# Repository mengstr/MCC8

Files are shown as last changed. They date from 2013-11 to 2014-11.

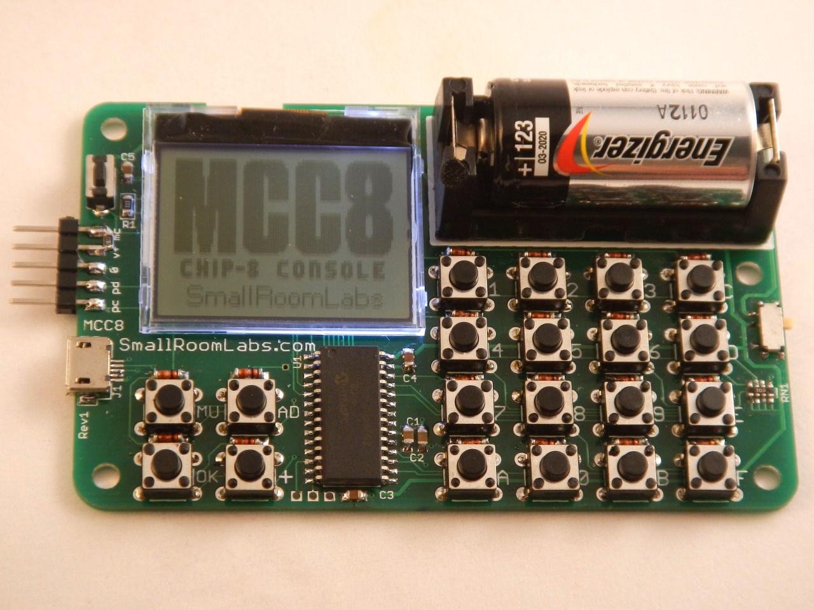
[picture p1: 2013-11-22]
Misc/BootScreen.jpg

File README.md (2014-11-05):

# MCC8

This is a small handheld PIC24-based CHIP-8 emulator game console. A cheap Noika 1202 LCD is used as the display and a CR123A 3 volt lithium battery for power. More info about the project can be found at [DangerousPrototypes.com](http://dangerousprototypes.com/forum/viewtopic.php?f=56&t=6018)



The sixteen buttons on the right is a hexadecimal keypad arranged in the same strange order as the COSMAC had for maximum keyplacement compability. Then I've added four extra buttons to go into game selection menu mode and other stuffs for future use. 

Read more about CHIP-8 at [Wikipedia](http://en.wikipedia.org/wiki/CHIP-8)

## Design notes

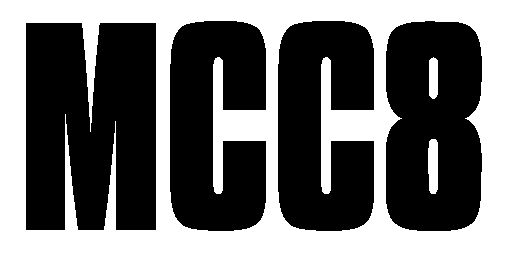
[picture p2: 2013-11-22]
Misc/mcc8.bmp

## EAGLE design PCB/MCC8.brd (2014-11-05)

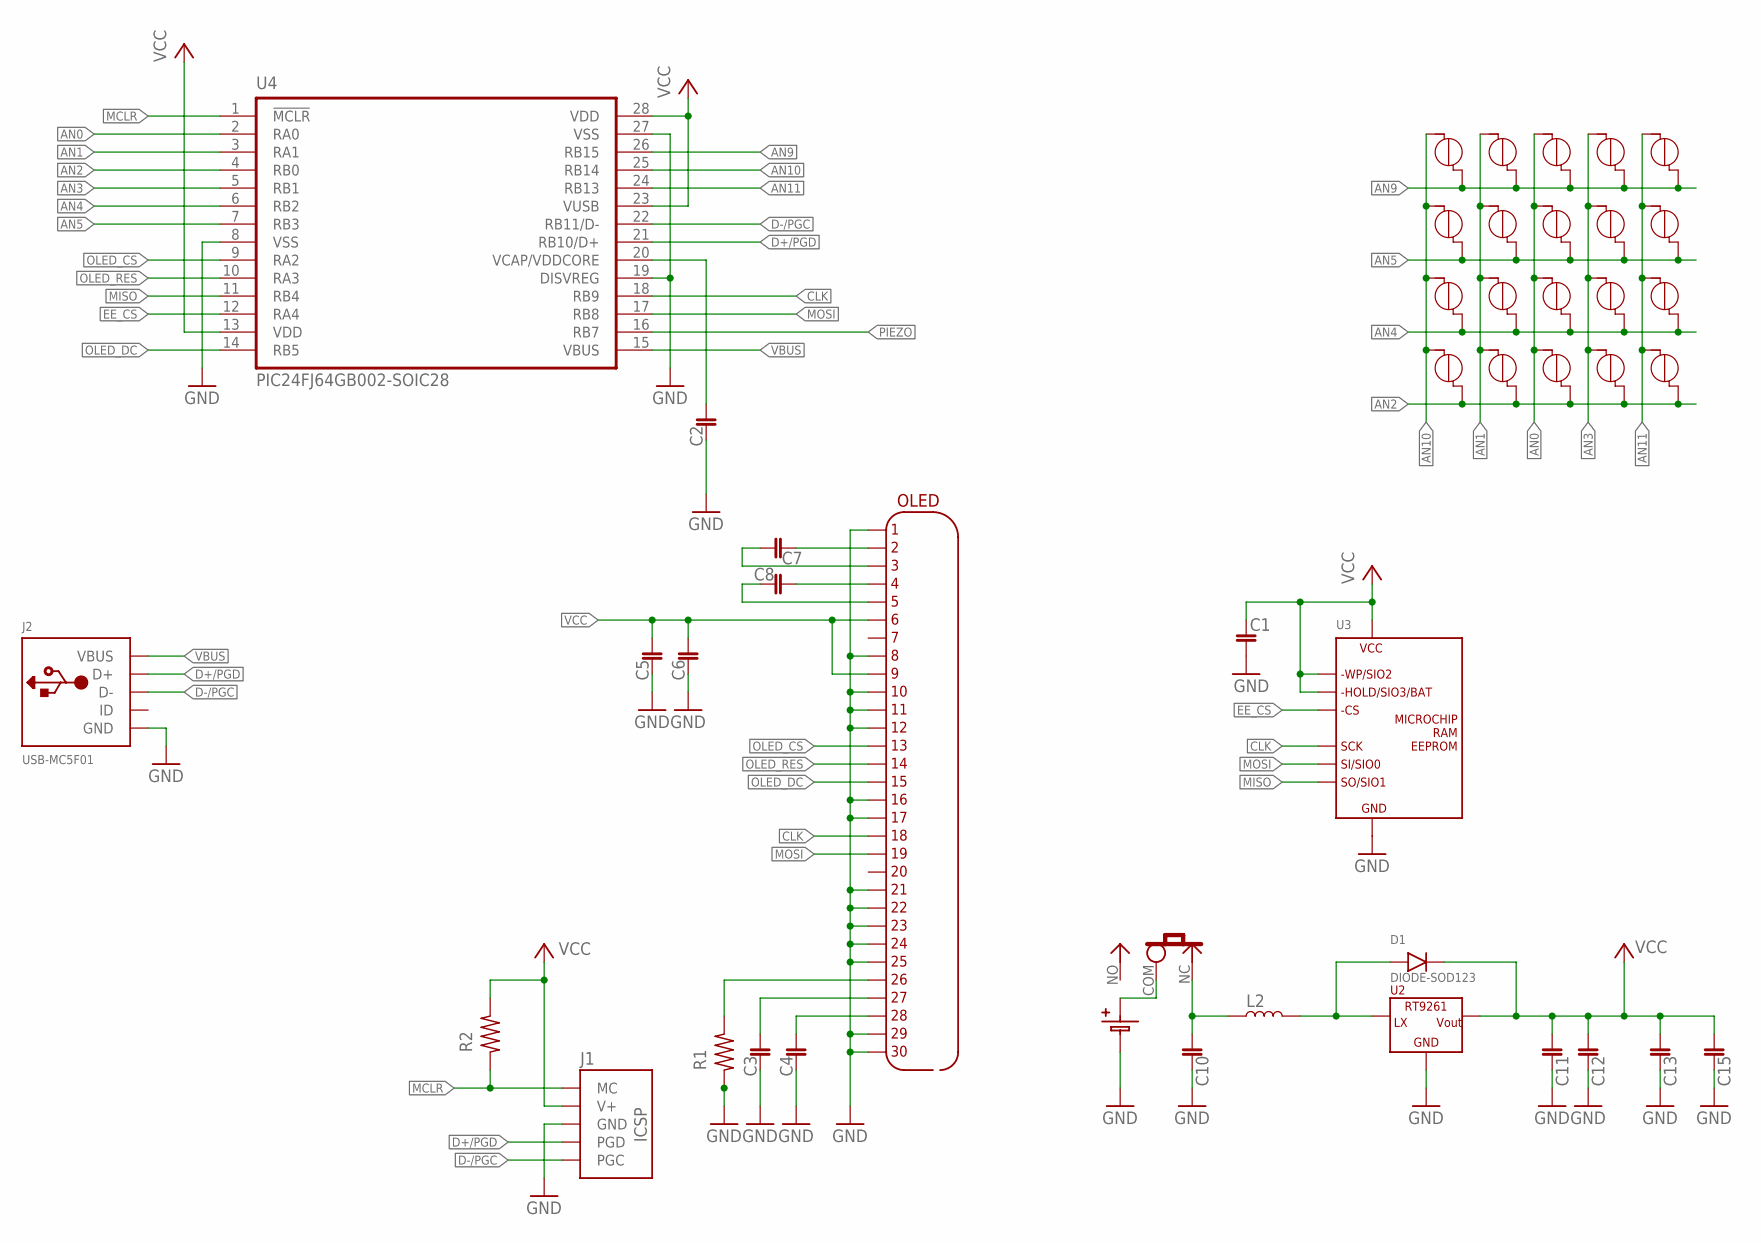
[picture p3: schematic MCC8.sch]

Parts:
B1, B2, B3, B4, B5, B6, B7, B8, B9, B10, B11, B12, B13, B14, B15, B16, B17, B18, B19, B20: TOUCH-CAP2-7; TOUCH-CAP2-7MM
BA2: BATTERY2-AAA1; BAT-AAA1
C1, C2, C3, C4, C5, C6, C7, C8, C10, C11, C12, C13, C15: C-0805; C0805
D1: DIODE-SOD123; SOD123
J1: ICSP-SMD-B
J2: USB-MC5F01; USB-MICRO-MC5F01
L2: L-BOURNS-SRP7030; IND-BOURNS-SRP7030
R1, R2: R-0805; R0805
SW1: SLIDE1-PCM12; SW-PCM12
U2: RT9261-SOT89; SOT89
U3: MICROCHIP-SERIALMEM8; SO08
U4: PIC24FJ64GB002-SOIC28; SO28W
U$2: OLED30-A; OLED128X64

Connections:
AN0: B9.P$1, B10.P$1, B11.P$1, B12.P$1, U4.2 (RA0)
AN1: B5.P$1, B6.P$1, B7.P$1, B8.P$1, U4.3 (RA1)
AN2: B4.P$2, B8.P$2, B12.P$2, B16.P$2, B20.P$2, U4.4 (RB0)
AN3: B13.P$1, B14.P$1, B15.P$1, B16.P$1, U4.5 (RB1)
AN4: B3.P$2, B7.P$2, B11.P$2, B15.P$2, B19.P$2, U4.6 (RB2)
AN5: B2.P$2, B6.P$2, B10.P$2, B14.P$2, B18.P$2, U4.7 (RB3)
AN9: B1.P$2, B5.P$2, B9.P$2, B13.P$2, B17.P$2, U4.26 (RB15)
AN10: B1.P$1, B2.P$1, B3.P$1, B4.P$1, U4.25 (RB14)
AN11: B17.P$1, B18.P$1, B19.P$1, B20.P$1, U4.24 (RB13)
BAT: BA2.PLUS (POS1), SW1.COM
BAT-SWITCHED: C10.1, L2.P$1, SW1.NC
CLK: U3.6 (SCK), U4.18 (RB9), U$2.P$18
D+/PGD: J1.PGD, J2.P3 (D+), U4.21 (RB10/D+)
D-/PGC: J1.PGC, J2.P2 (D-), U4.22 (RB11/D-)
EE_CS: U3.1 (CS), U4.12 (RA4)
GND: BA2.MINUS (NEG), C1.2, C2.2, C3.2, C4.2, C5.2, C6.2, C10.2, C11.2, C12.2, C13.2, C15.2, J1.GND, J2.P5 (GND), R1.1, U2.1 (GND), U3.4 (GROUND), U4.8 (VSS), U4.19 (DISVREG), U4.27 (VSS), U$2.P$1, U$2.P$8, U$2.P$10, U$2.P$11, U$2.P$12, U$2.P$16, U$2.P$17, U$2.P$21, U$2.P$22, U$2.P$23, U$2.P$24, U$2.P$25, U$2.P$29, U$2.P$30
LX: D1.A, L2.P$2, U2.3 (LX)
MCLR: J1.VPP (MC), R2.1, U4.1 (!MCLR)
MISO: U3.2 (SO), U4.11 (RB4)
MOSI: U3.5 (SI), U4.17 (RB8), U$2.P$19
unnamed: C4.1, U$2.P$28
unnamed: C3.1, U$2.P$27
unnamed: R1.2, U$2.P$26
unnamed: C7.2, U$2.P$2
unnamed: C7.1, U$2.P$3
unnamed: C8.1, U$2.P$4
unnamed: C8.2, U$2.P$5
OLED_CS: U4.9 (RA2), U$2.P$13
OLED_DC: U4.14 (RB5), U$2.P$15
OLED_RES: U4.10 (RA3), U$2.P$14
PIEZO: U4.16 (RB7)
VBUS: J2.P1 (VBUS), U4.15 (VBUS)
VCC: C1.1, C5.1, C6.1, C11.1, C12.1, C13.1, C15.1, D1.C, J1.V+, R2.2, U2.2 (VOUT), U2.2@1 (VOUT), U3.3 (WP), U3.7 (HOLD), U3.8 (POW), U4.13 (VDD), U4.23 (VUSB), U4.28 (VDD), U$2.P$6, U$2.P$9
VDDCORE: C2.1, U4.20 (VCAP/VDDCORE)

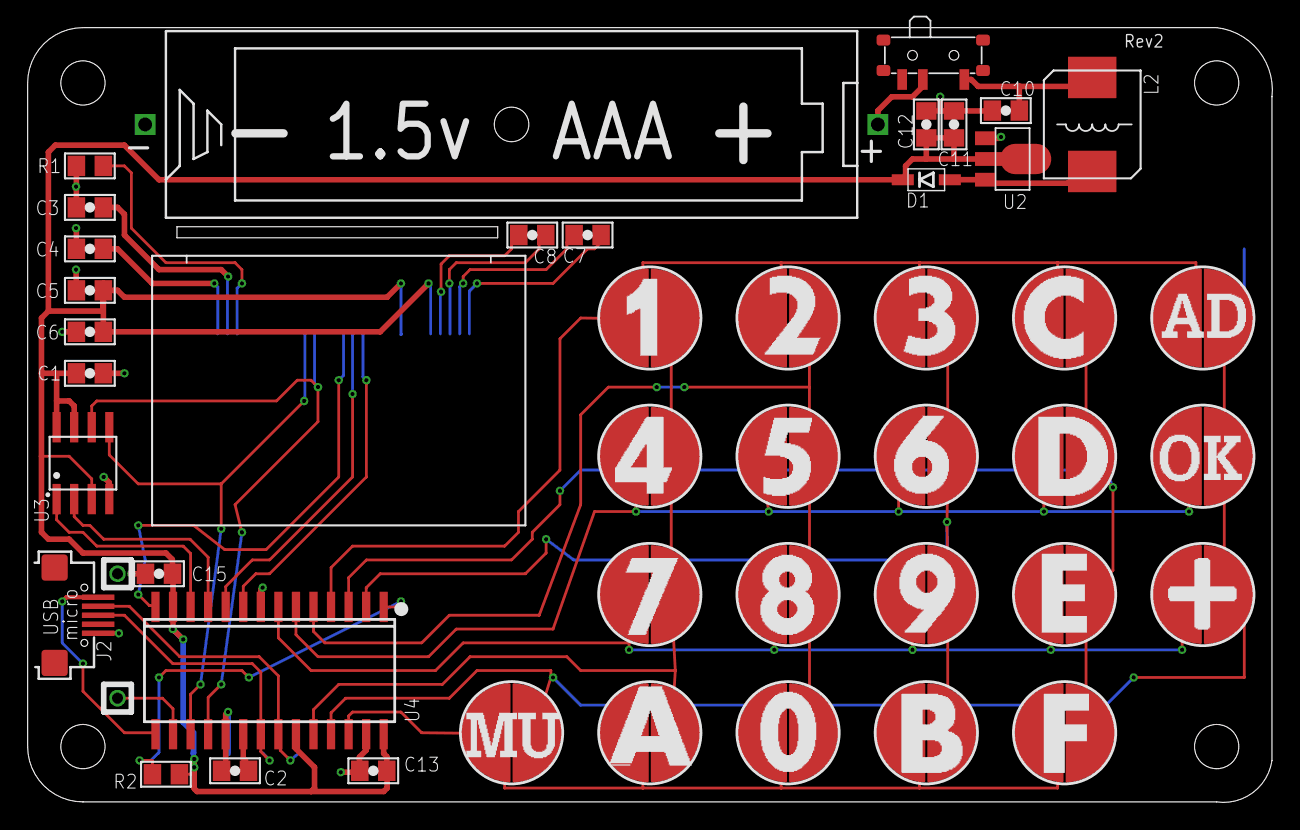
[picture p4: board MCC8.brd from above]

Board: 2 copper layers, 90.0 x 56.0 mm, 45 parts (1 on the bottom side), 33 nets.

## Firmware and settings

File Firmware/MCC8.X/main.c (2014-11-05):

#include <stdlib.h>
#include <stdint.h>         // uint8_t definitions
#include <stdbool.h>        // true/false definitions
#include <stdio.h>

#include <xc.h>
#include "config.h"
#include "spi.h"
#include "oled.h"
#include "eeprom.h"
#include "key.h"
#include "games.h"
#include "chip8.h"


/*
 *
 * http://www.pong-story.com/chip8/
 * http://www.zophar.net/pdroms/chip8/chip-8-games-pack.html
 * view-source:http://www.markoskyritsis.com/index.php/open-source-development/chip8-online-emulator
 * http://www.emulator101.com/
 * http://www.multigesture.net/articles/how-to-write-an-emulator-chip-8-interpreter/
 * http://devernay.free.fr/hacks/chip8/C8TECH10.HTM#2.5
 * http://mattmik.com/chip8.html
 * http://newsdee.com/flip8/
 * 
 *
 * LCD display is 128x64 pixels so each CHIP-8 pixel can be 2x2 pixels
 * on the display
 *
*/



//
//
//
uint8_t ShowGameMenu(void) {
    uint8_t i;
    uint8_t mnu=0;
    uint8_t realKey;

    for (;;) {
        OledClear();
        if (mnu==0) {
            for (i=0; i<8; i++) {
                OledXY(0,i*8);
                OledCharacter((char)49+i);
                OledXY(10,i*8);
                OledString(games[i].gameName);
            }
        }
        if (mnu==1) {
            for (i=0; i<8; i++) {
                OledXY(0,i*8);
                OledCharacter((char)49+i);
                OledXY(10,i*8);
                OledString(games[i+8].gameName);
            }
        }
        if (mnu==2) {
            for (i=0; i<7; i++) {
                OledXY(0,i*8);
                OledCharacter(49+i);
                OledXY(10,i*8);
                OledString(games[i+16].gameName);
            }
        }
        if (mnu==3) {
            OledXY(0,0);
            OledCharacter('F');
            OledXY(10,0);
            OledString("Toggle Debug");
        }
        OledRefresh();
        for(;;) {
            KeyScan();
            realKey=KeyTranslateKeys(keys);
            if (keysX&KEY_MU) {
                mnu++;
                if (mnu>3) mnu=0;
                OledClear();
                OledRefresh();
                KeyWaitForRelease();
                break;
            }
            if (mnu==0 && realKey>0 && realKey<9) return realKey+0-1;
            if (mnu==1 && realKey>0 && realKey<9) return realKey+8-1;
            if (mnu==2 && realKey>0 && realKey<8) return realKey+16-1;
        }

    }
    return 0;
}

//char gameName[23][9] = {
//const unsigned char *gamePtr[23] = {
//const uint16_t gameLength[23] = {

//
//
//
void InitTimer1(void) {
  T1CON	 = 0x8010;
  _T1IE	 = 1;
  _T1IF	 = 0;
  IPC0	 = IPC0 | 0x1000;
  PR1	 = 8333;
}



//
// Timer 1 interrupt service routine
//
void __attribute__((__interrupt__, __auto_psv__)) _T1Interrupt(void) {
    IFS0bits.T1IF = 0;      // Clear Timer 1 interrupt flag
    Chip8HandleTimers();
}





//
//
//
int main(void) {
    uint8_t res;

    AD1PCFG=0xEFFF;         // All pins are Digital

    // Set pins as output mode
    OLED_DC_TRIS=0;
    OLED_CS_TRIS=0;
    OLED_RES_TRIS=0;
    EE_CS_TRIS=0;
    PIEZO_TRIS=0;

    // Disable CS for both devices on the SPI bus
    OLED_CS=1;
    EE_CS=1;

    SPI1Init();             // Initialize the SPI1 port
    OledInit();             // Initialize/Reset the OLED display
    OledRefresh();
    InitTimer1();           // Start the 60 Hz chip-8 timer
    KeyInit();
    __delay_ms(100);

    chip8debug=0;
    
    for (;;) {
        res=ShowGameMenu();
        Chip8Reset(games[res].gamePtr, games[res].gameLength);
//        LcdFill();
        Chip8RefreshScreen();
        res=Chip8Emulate();
    }
}

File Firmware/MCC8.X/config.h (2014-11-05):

#ifndef CONFIG_H_
#define	CONFIG_H_

#include <stdlib.h>
#include <stdint.h>
#include <xc.h>

#define _XTAL_FREQ (8000000ULL)
#define FCY (_XTAL_FREQ/2)

extern void __delay32(unsigned long cycles);

#define __delay_ms(d) \
  { __delay32( (unsigned long) (((unsigned long long) d)*(FCY)/1000ULL)); }


#define __delay_us(d) \
  { __delay32( (unsigned long) (((unsigned long long) d)*(FCY)/1000000ULL)); }

#define  testbit(var, bit)   ((var) & (1UL <<(bit)))
#define  setbit(var, bit)    ((var) |= (1UL << (bit)))
#define  clrbit(var, bit)    ((var) &= ~(1UL << (bit)))


#define OLED_DC_TRIS    TRISBbits.TRISB5
#define OLED_CS_TRIS    TRISAbits.TRISA2
#define OLED_RES_TRIS   TRISAbits.TRISA3
#define EE_CS_TRIS      TRISAbits.TRISA4
#define PIEZO_TRIS      TRISBbits.TRISB7

#define OLED_DC         LATBbits.LATB5
#define OLED_CS         LATAbits.LATA2
#define OLED_RES        LATAbits.LATA3
#define EE_CS           LATAbits.LATA4
#define PIEZO           LATBbits.LATB7

#define TOUCH0_TRIS     TRISAbits.TRISA0
#define TOUCH1_TRIS     TRISAbits.TRISA1
#define TOUCH2_TRIS     TRISBbits.TRISB0
#define TOUCH3_TRIS     TRISBbits.TRISB1
#define TOUCH4_TRIS     TRISBbits.TRISB2
#define TOUCH5_TRIS     TRISBbits.TRISB3
#define TOUCH6_TRIS     TRISBbits.TRISB15
#define TOUCH7_TRIS     TRISBbits.TRISB14
#define TOUCH8_TRIS     TRISBbits.TRISB13

#define TOUCH0          LATAbits.LATA0
#define TOUCH1          LATAbits.LATA1
#define TOUCH2          LATBbits.LATB0
#define TOUCH3          LATBbits.LATB1
#define TOUCH4          LATBbits.LATB2
#define TOUCH5          LATBbits.LATB3
#define TOUCH6          LATBbits.LATB15
#define TOUCH7          LATBbits.LATB14
#define TOUCH8          LATBbits.LATB13

#endif

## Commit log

2013-11-22 PCB Rev1
    [MCC8.GBL, MCC8.GBO, MCC8.GBP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]
2013-11-22 Broke out emulation in main.c to chip8.c
    [main.c]
2013-11-22 c8st and c8dt is now handled by 60 Hz timer1 interrupt
2013-11-22 Image of PCB
2014-11-05 Gerbers & Eagle for last version of LCD
    [MCC8.GBL, MCC8.GBO, MCC8.GBP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]
2014-11-05 Eagle files for OLED
    [MCC8.brd, MCC8.sch]
2014-11-05 Gebers for OLED version
    [MCC8.GBL, MCC8.GBO, MCC8.GBP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]

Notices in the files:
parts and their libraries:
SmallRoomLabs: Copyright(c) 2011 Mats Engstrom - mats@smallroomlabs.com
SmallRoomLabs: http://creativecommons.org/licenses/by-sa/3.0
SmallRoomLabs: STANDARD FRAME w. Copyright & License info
